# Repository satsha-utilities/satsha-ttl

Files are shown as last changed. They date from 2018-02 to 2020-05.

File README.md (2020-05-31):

<div align="center"><h1 style="font-family: courier;" align="center">satsha-ttl</h1></div>

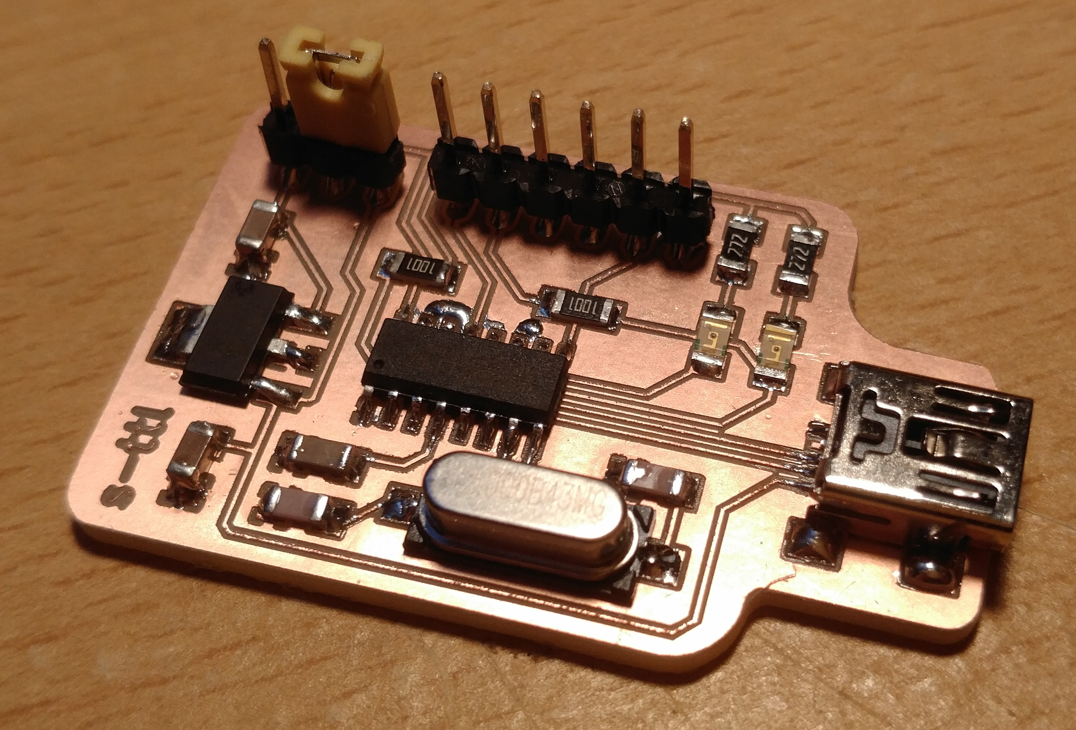
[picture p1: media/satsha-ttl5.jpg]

<div align="center"><i>An open source & fabbable USB to serial converter board.</i></div>

satsha-ttl
--

After some time of buying expensive FDTI cables (about 20$ nowadays) and having the need to use several USB to serial converters for my **[Fab Academy](http://fabacademy.org/)** students, I developed my own fabbable solution. satsha-ttl features a **[CH340G USB to serial chip](https://cdn.sparkfun.com/datasheets/Dev/Arduino/Other/CH340DS1.PDF)** and it is designed to be cheap, reliable and easy to be reproduced. It uses an LDO voltage regulator and a **jumper to switch between 3.3V and 5V**, both for power and logic levels of TX/RX. The design of the satsha-ttl also allows to easily integrate it into existing boards requiring an USB communication without having a dedicated hardware implemented into the microcontroller (eg the 328p).

Here are the **features of the satsha-ttl:**

- **CH340G** USB to serial chip
- selectable voltage of **3.3V and 5V** (both for power and serial)
- **250mA** current on 3.3V
- **USB power** for 5V
- **CTS and DTR** pins
- **mini USB** connector
- **no drivers** needed for latest Windows/MacOS/Linux
- size of **45x28mm**
- cost **1.3€/1.6$** (buying the components from China, **[BOM](https://gitlab.fabcloud.org/satsha/satsha-ttl/raw/master/docs/satsha-ttl-BOM.xlsx)**)

satsha-ttl **PCB**:

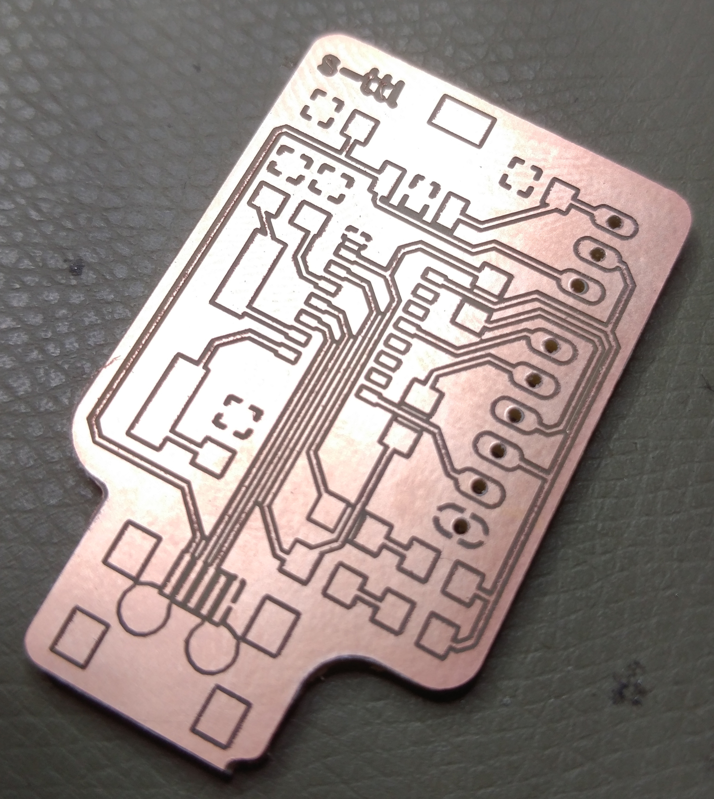
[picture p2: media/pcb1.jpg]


satsha-ttl **schematic**:

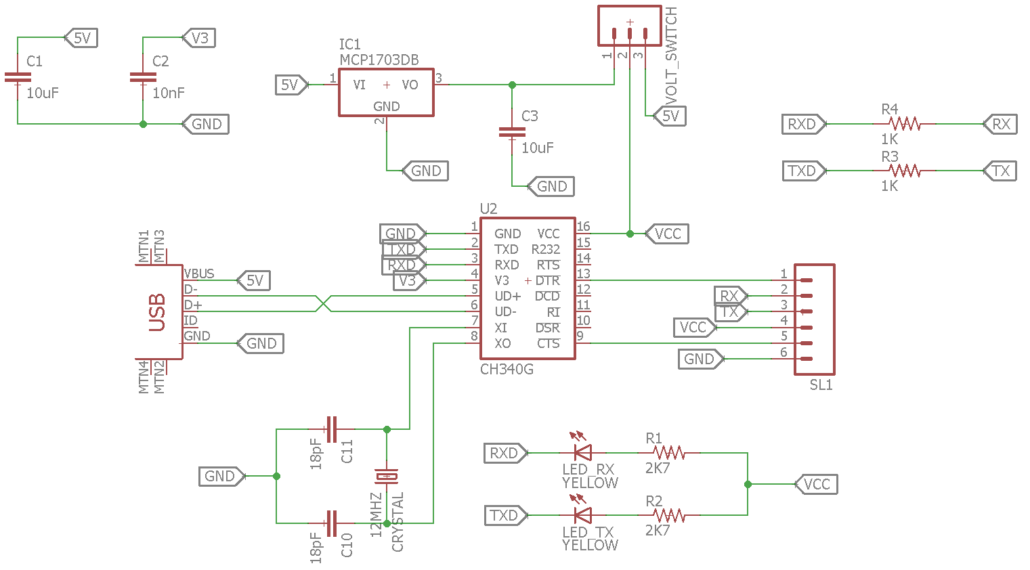
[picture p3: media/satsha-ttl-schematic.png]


satsha-ttl **board**:

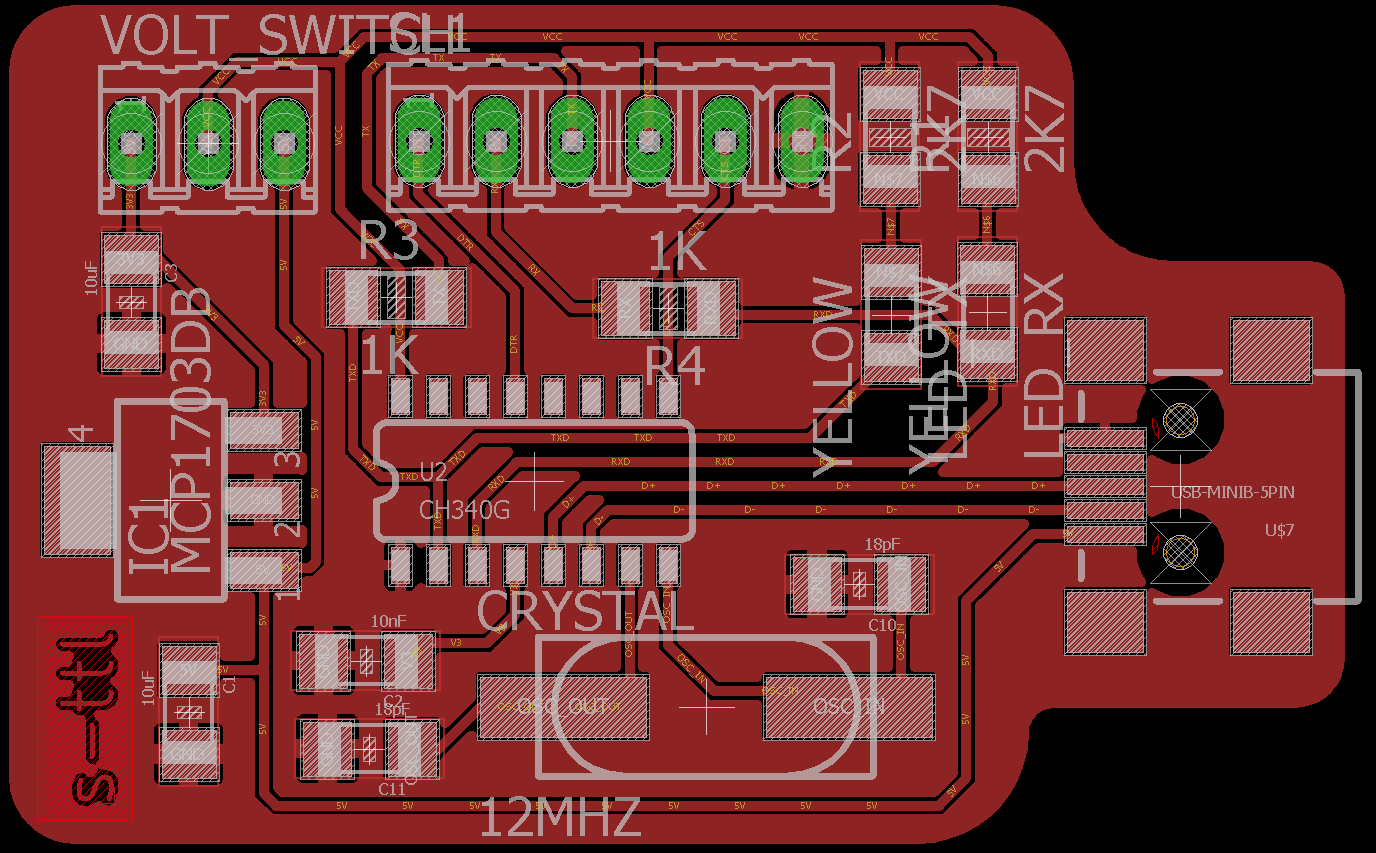
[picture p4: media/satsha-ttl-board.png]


Downloads
--

**downloads (right click download as):**

- **[satsha-ttl schematic](https://github.com/satsha-utilities/satsha-ttl/raw/master/eagle/satsha-ttl/satsha-ttl.sch)**
- **[satsha-ttl board](https://github.com/satsha-utilities/satsha-ttl/raw/master/eagle/satsha-ttl/satsha-ttl.brd)**
- **[satsha-ttl internal traces png 0.1mm](https://github.com/satsha-utilities/satsha-ttl/raw/master/media/internal.png)**
- **[satsha-ttl cutout png 0.1mm](https://github.com/satsha-utilities/satsha-ttl/raw/master/media/cut.png)**
- **[satsha-ttl internal traces png 0.2mm](https://github.com/satsha-utilities/satsha-ttl/raw/master/media/internal_02.png)**
- **[satsha-ttl cutout png 0.2mm](https://github.com/satsha-utilities/satsha-ttl/raw/master/media/cut_02.png)**
- **[satsha-ttl BOM ods](https://github.com/satsha-utilities/satsha-ttl/raw/master/docs/satsha-ttl-BOM.ods)**
- **[satsha-ttl BOM xlsx](https://github.com/satsha-utilities/satsha-ttl/raw/master/docs/satsha-ttl-BOM.xlsx)**

Getting started with satsha-ttl
--
Before connecting satsha-ttl to your computer is really important to **check if the connections are ok**, as it could damage the USB port of our computer if they are wrong. A smoke test can also be done beforehand with an **USB hub or an USB power supply**.  Install the **drivers** for the CH340G if satsha-ttl is not recognized automatically from your OS. In case you are using Windows 8 or older, or older versions of MacOS/Linux download and install the **[drivers from here](https://sparks.gogo.co.nz/ch340.html)**. 

 Find below the **satsha-ttl pinout**:

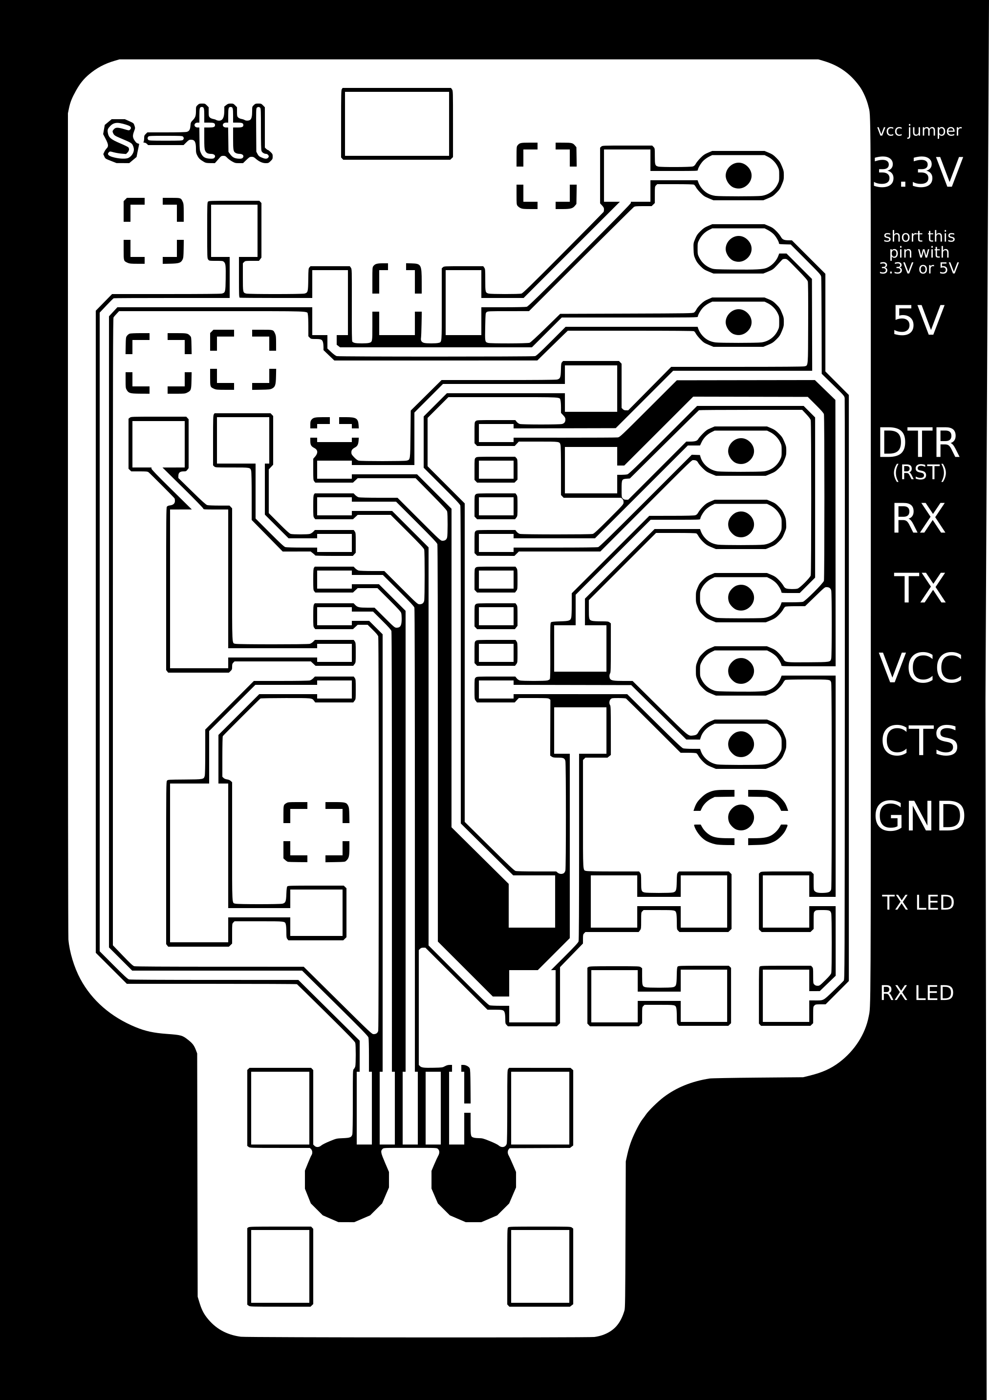
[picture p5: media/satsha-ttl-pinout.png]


satsha-ttl can be used to **supply power** to another microcontroller board, other than connecting the serial. In case of supplying power to another board make sure its voltage and current requirements matches the **selected voltage** on the satsha-ttl jumper and the **maximum current** the satsha-ttl/USB port can output. It is possible to use the satsha-ttl as a **programmer for AVR** microcontrollers with installed the Arduino bootloader, in this case the **DTR** is used **software reset** pin.

Here is an example scheme on how to connect **satsha-ttl to program a satshakit:**

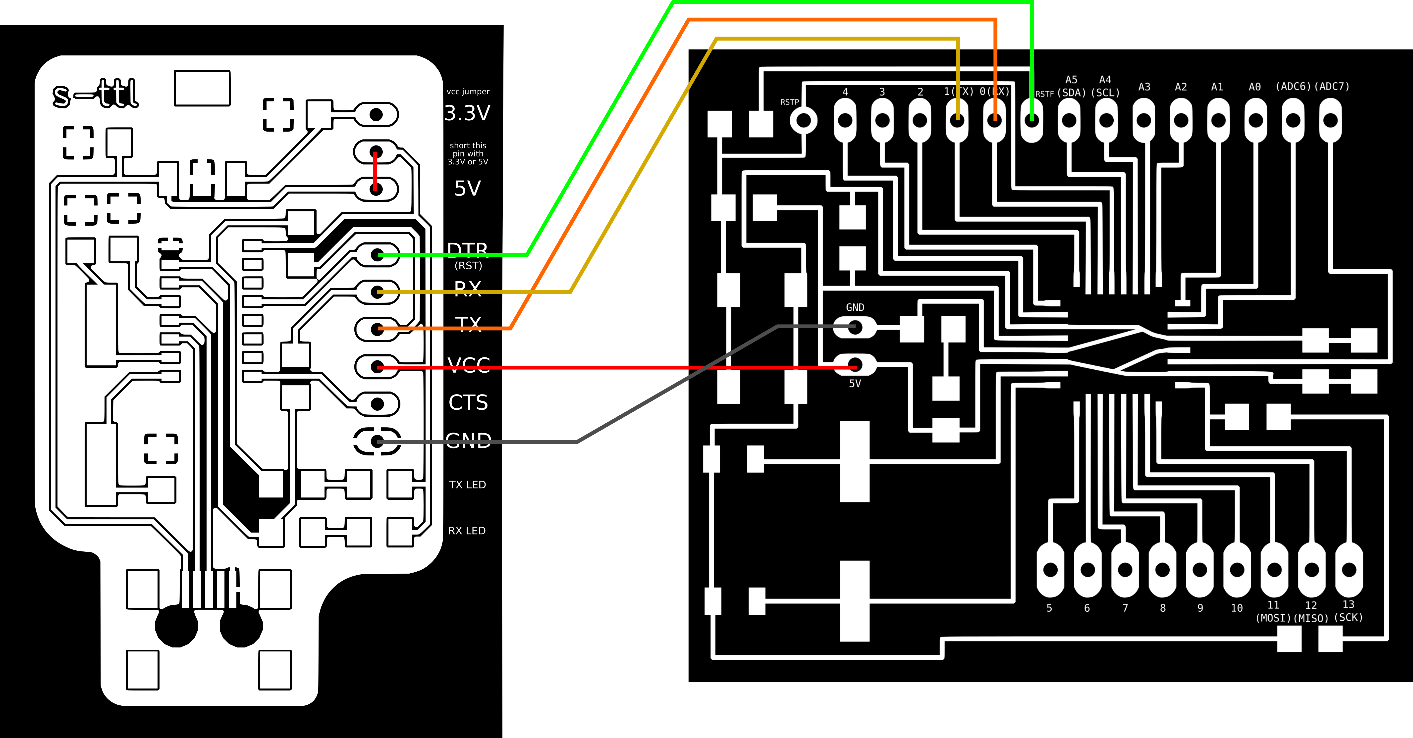
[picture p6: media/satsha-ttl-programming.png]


Media
--

satsha-ttl pictures:

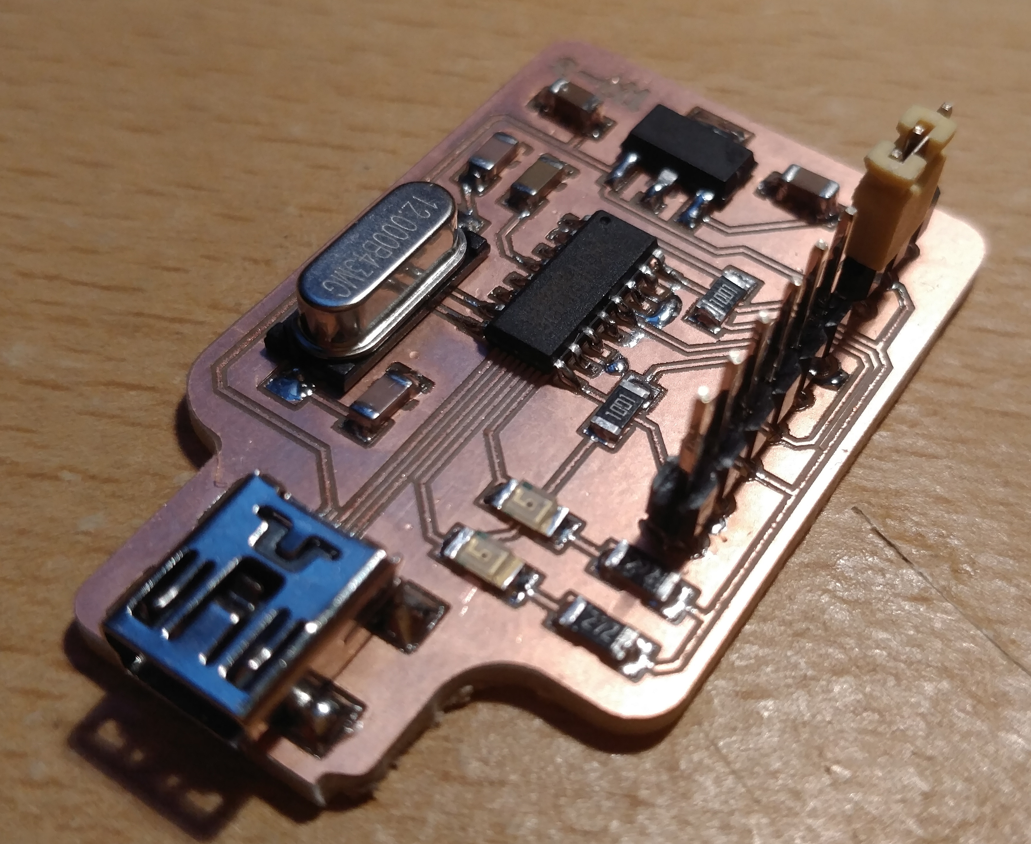
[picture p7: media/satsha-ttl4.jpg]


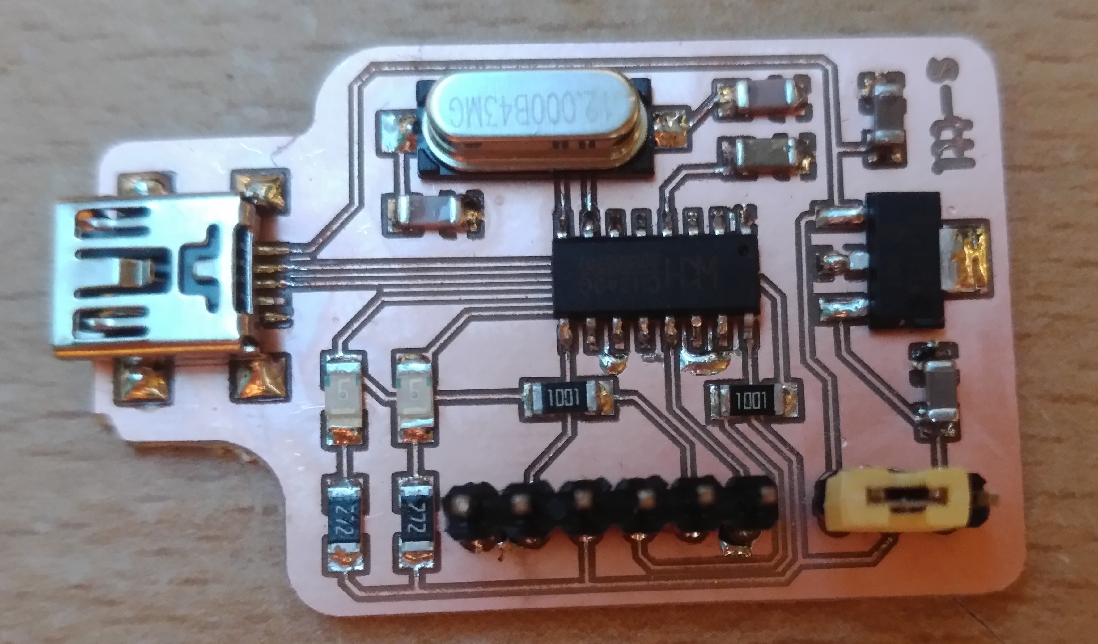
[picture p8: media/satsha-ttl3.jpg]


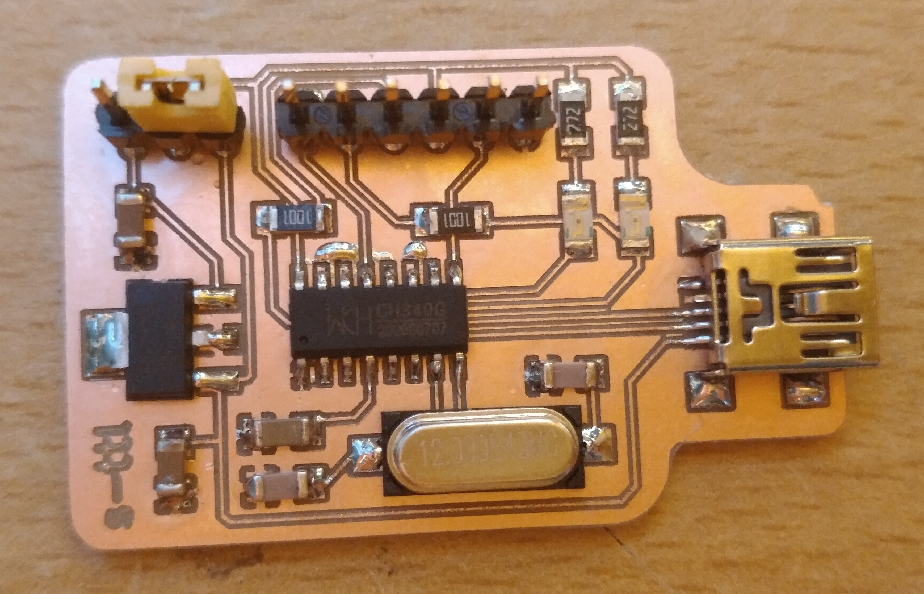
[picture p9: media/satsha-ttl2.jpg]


satsha-ttl connected with a satshakit:

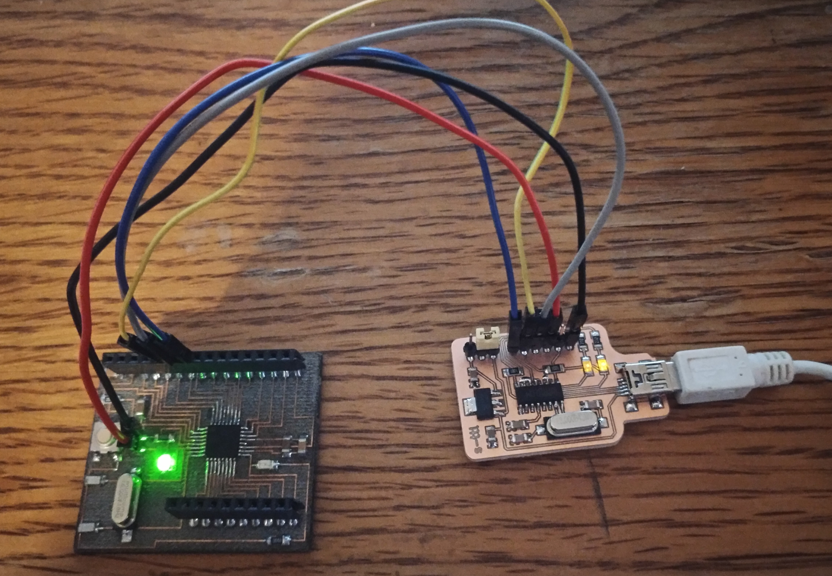
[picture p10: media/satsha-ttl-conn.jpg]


satsha-ttl 1 million lines gcode test:

<a href="http://www.youtube.com/watch?feature=player_embedded&v=dIH6fnEvGS4
" target="_blank"></a>

satsha-ttl 2 uploading to a satshakit using serial 5V:

<a href="http://www.youtube.com/watch?feature=player_embedded&v=kN5nttG7nbE
" target="_blank"></a>

satsha-ttl receiving data from software serial 3.3V:

<a href="http://www.youtube.com/watch?feature=player_embedded&v=gNB7xQKvWcM
" target="_blank"></a>

satsha-ttl streaming gcode to grbl satshakit @250000 bauds 5V:

<a href="http://www.youtube.com/watch?feature=player_embedded&v=7HWK96QzLX8
" target="_blank"></a>

Author
--

- Daniele Ingrassia

Contact
--
- **ingrassiada@gmail.com**
- **[linkedin](http://it.linkedin.com/in/danieleingrassia)**

Thanks
--
[Fablab Kamp-Lintfort](http://fablab.hochschule-rhein-waal.de/index.php/de/)<br />
Hochschule Rhein-Waal<br />
Friedrich-Heinrich-Allee 25, 47475 Kamp-Lintfort, Germany<br />
fablab@hochschule-rhein-waal.de

License
--
This work is licensed under the terms of the open source license: Creative Commons Attribution-ShareAlike 4.0 International ([CC BY-SA 4.0](https://creativecommons.org/licenses/by-sa/4.0/)).

Disclaimer  
--

<div class="align-justify">
This hardware/software is provided "as is", and you use the hardware/software at your own risk. Under no circumstances shall any author be liable for direct, indirect, special, incidental, or consequential damages resulting from the use, misuse, or inability to use this hardware/software, even if the authors have been advised of the possibility of such damages.</div>

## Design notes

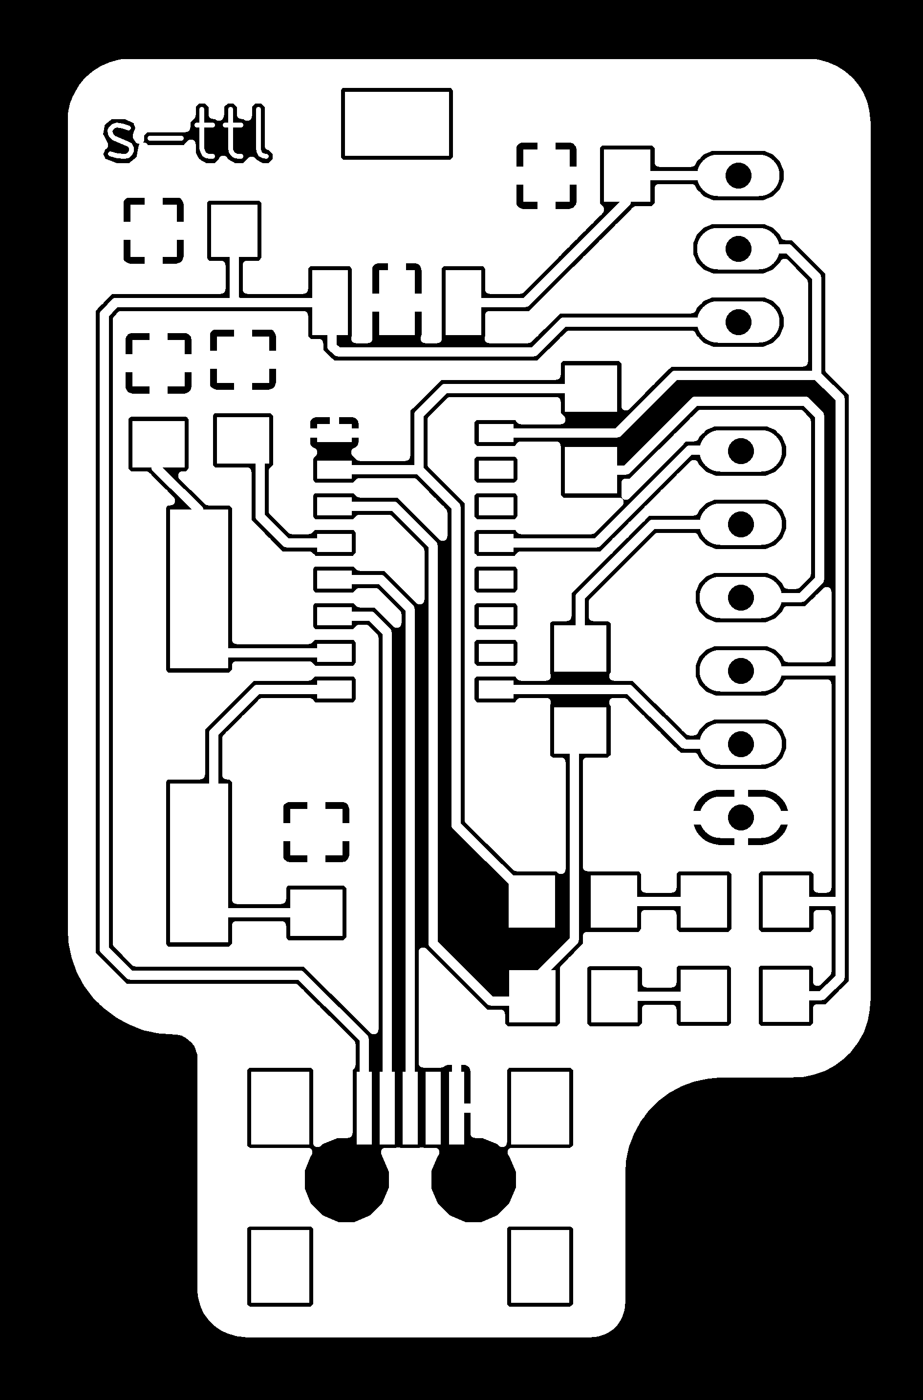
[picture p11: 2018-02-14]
media/internal.png

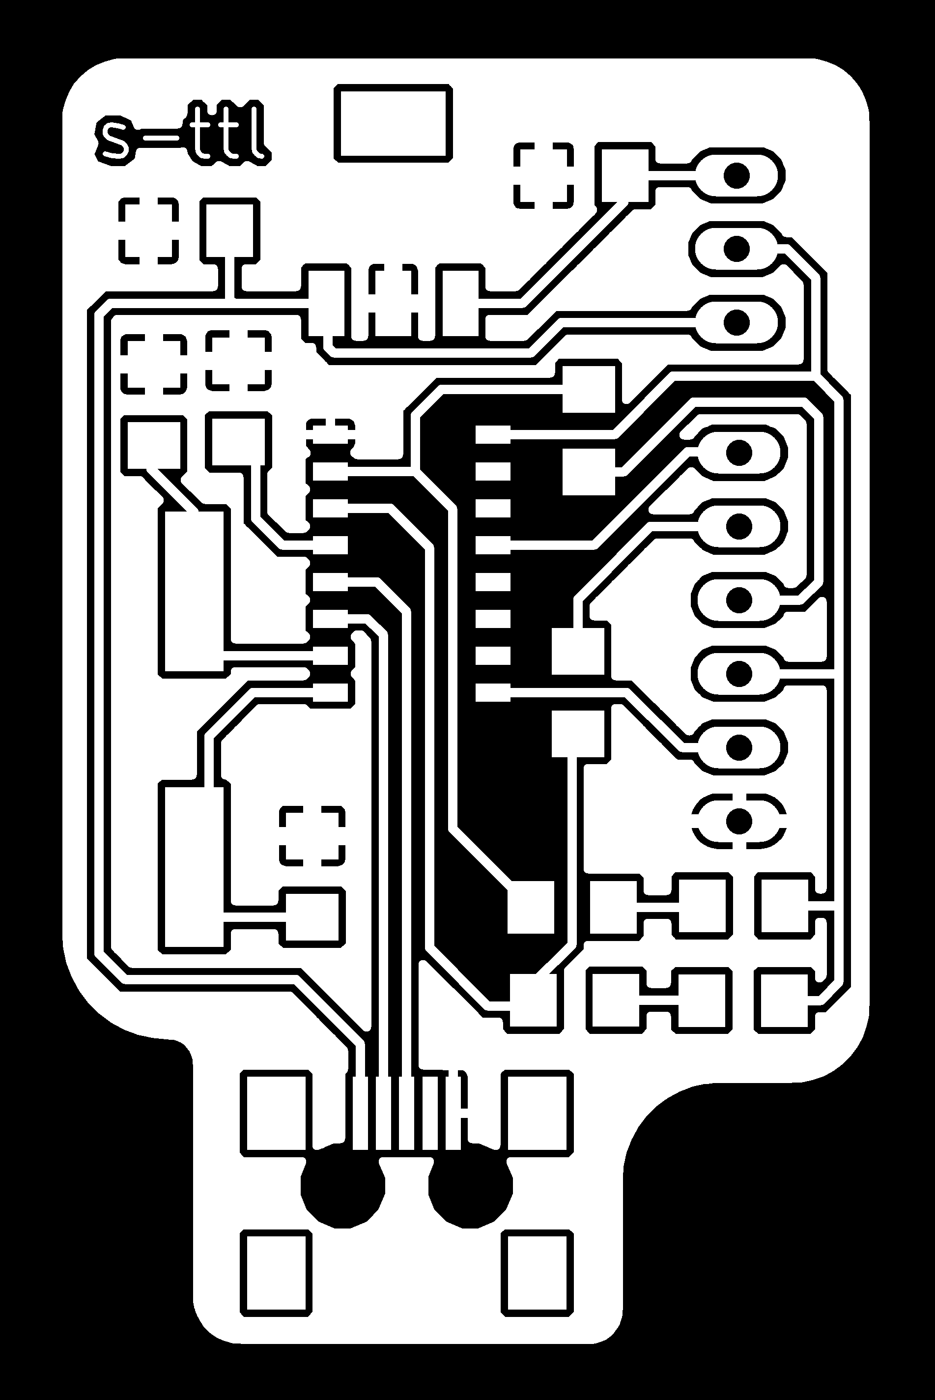
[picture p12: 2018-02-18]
media/internal_02.png

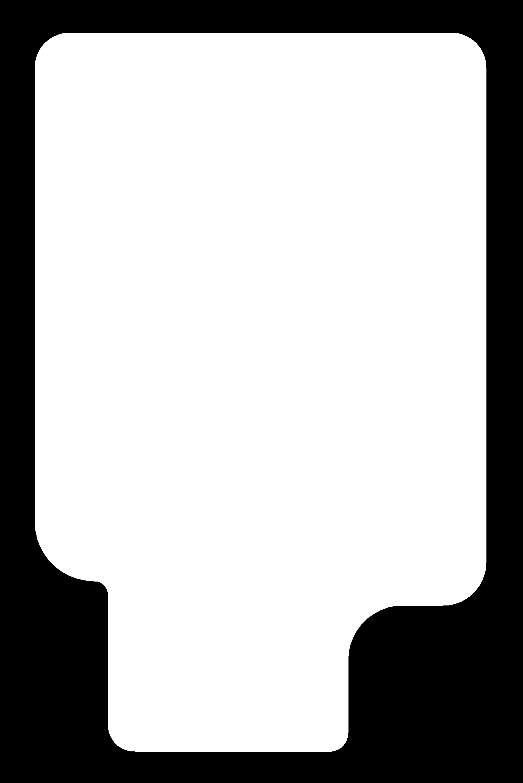
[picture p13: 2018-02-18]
media/cut_02.png

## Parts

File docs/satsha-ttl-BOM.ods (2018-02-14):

Quantity | Description | Unit Price | Extended Price
1 | Mini USB connector (https://www.aliexpress.com/item/ZLinKJ-Wholesale-10pcs-lot-Mini-Usb-Connector-Micro-USB-Connector-5pin-Seat-Jack-Micro-Usb-Four/32840263513.html) | 0.043 | 0.04€
2 | Yellow LED 1206 (https://www.aliexpress.com/item/50PCS-Free-Shipping-SMD-1206-LED-YELLOW-Ultra-Bright-SMD-LEDs-1206-yellow-1206-Diodes-light/1000004897034.html) | 0.0092 | 0.02€
2 | Capacitor 18pF 1206 (https://www.aliexpress.com/item/1206-18PF-50V-180J-5-100pcs-lot-Free-shipping-SMD-ceramic-capacitors/32826160763.html) | 0.018 | 0.04€
1 | Capacitor 10nF 1206 (https://www.aliexpress.com/item/500PCS-1206-103-10NF-0-01UF-X7R-10-smd-chip-capacitor/1478495946.html) | 0.0096 | 0.01€
2 | Resistor 1K 1206 (https://www.aliexpress.com/item/Free-Shipping-100PCS-1206-1K-1K-OHM-1-smd-resistor/1090880725.html) | 0.0074 | 0.01€
1 | Pin Header 0.1" 40pos (https://www.aliexpress.com/item/10pcs-40-Pin-1x40-Single-Row-Male-2-54-Breakable-Pin-Header-Connector-Strip-for-Arduino/32555149083.html) | 0.045 | 0.05€
2 | Resistor 2K71206 (https://www.aliexpress.com/item/200pcs-lot-SMD-Chip-Resistor-1206-2K-2-2K-2-4K-2-7K-3K-Ohm-5/32832679594.html) | 0.0041 | 0.01€
1 | Crystal 12Mhz (https://www.aliexpress.com/item/1LOT-10PCS-Crystal-12MHZ-20PF-20PPM-2P-49SMD-SeriesHC-49SMD/32536483181.html) | 0.195 | 0.20€
2 | Capacitor 10uF 1206 (https://www.aliexpress.com/item/Free-shipping-100pcs-1206-10uF-16V-20-Y5V-Ceramic-SMD-Capacitor/1225771436.html) | 0.0102 | 0.02€
1 | 0.1" Jumper (https://www.aliexpress.com/item/OOTDTY-100-Pcs-2-54mm-Standard-Jumper-Blocks-Caps-For-Hard-Drive-CD-DVD-Motherboards-High/32845598684.html) | 0.0066 | 0.01€
1 | MCP1703DB 3.3V 250mA Regulator (https://www.aliexpress.com/item/MCP1703T-3302E-DB-MCP1703T-3302E-D-MCP1703T-3302E-MCP1703T-3302-3302-10pcs-lot/32762444428.html) | 0.261 | 0.26€
1 | CH340G Usb to Serial converter (https://www.aliexpress.com/item/Free-shipping-1pcs-CH340G-CH340-SOP-16-The-new-quality-is-very-good-work-100-of/32838726117.html) | 0.62 | 0.62€
 |  | Total: | 1.28€

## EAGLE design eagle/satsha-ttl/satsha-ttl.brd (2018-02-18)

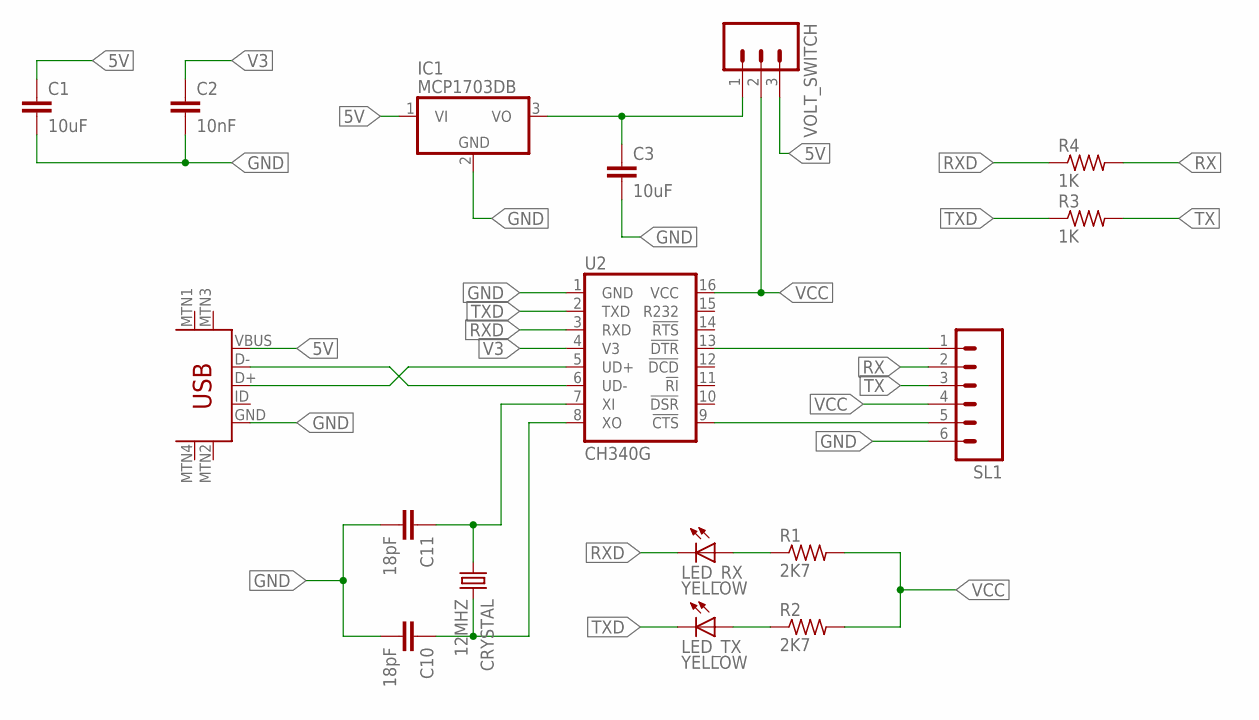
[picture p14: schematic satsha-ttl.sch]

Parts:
C1, C3: 10uF; 1206
C2: 10nF; 1206
C10, C11: 18pF; 1206
CRYSTAL: 12MHZ; CSM-7X-DU
IC1: MCP1703DB; SOT223
LED_RX: YELLOW; LED1206
LED_TX: YELLOW; LED1206
R1, R2: 2K7; R1206
R3, R4: 1K; R1206
SL1: M06; 06P
U2: CH340G; SO016
U$7: USB-MINIB-5PIN; USB-MINIB
VOLT_SWITCH: M03; 03P

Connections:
3V3: C3.1, IC1.3 (VO), VOLT_SWITCH.1
5V: C1.1, IC1.1 (VI), U$7.VBUS, VOLT_SWITCH.3
CTS: SL1.5, U2.9 (!CTS)
D+: U2.5 (UD+), U$7.D+
D-: U2.6 (UD-), U$7.D-
DTR: SL1.1, U2.13 (!DTR)
GND: C1.2, C2.2, C3.2, C10.2, C11.2, IC1.2 (GND), SL1.6, U2.1 (GND), U$7.GND
unnamed: LED_RX.1 (A), R1.1
unnamed: LED_TX.1 (A), R2.1
OSC_IN: C10.1, CRYSTAL.2, U2.8 (XO)
OSC_OUT: C11.1, CRYSTAL.1, U2.7 (XI)
RX: R4.2, SL1.2
RXD: LED_RX.2 (C), R4.1, U2.3 (RXD)
TX: R3.2, SL1.3
TXD: LED_TX.2 (C), R3.1, U2.2 (TXD)
V3: C2.1, U2.4 (V3)
VCC: R1.2, R2.2, SL1.4, U2.16 (VCC), VOLT_SWITCH.2

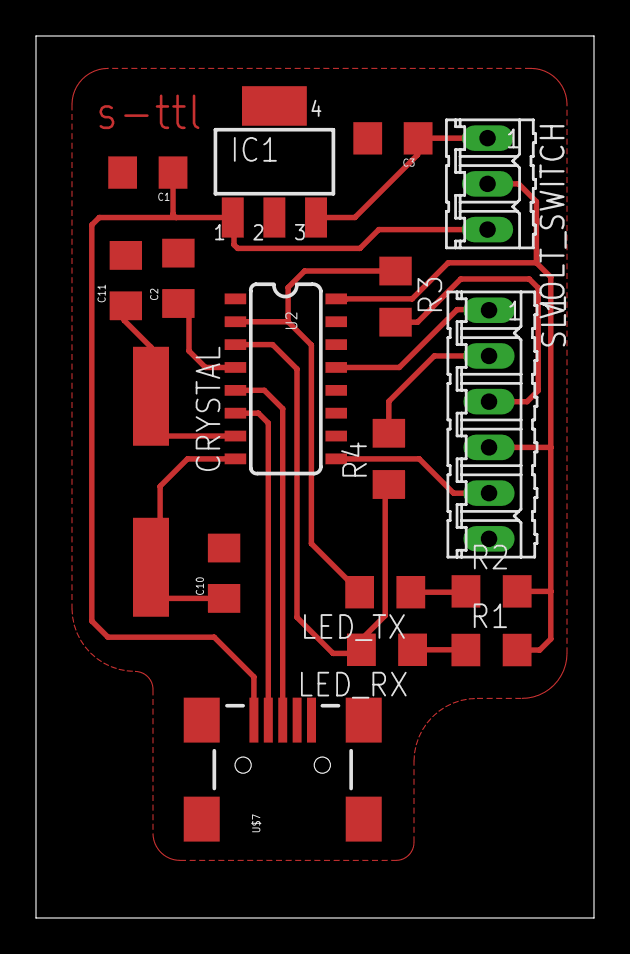
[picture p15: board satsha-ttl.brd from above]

Board: 2 copper layers, 31.0 x 49.0 mm, 17 parts (0 on the bottom side), 17 nets.

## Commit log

2018-02-14 first commit imported from Fab Academy gitlab
    [satsha-ttl-BOM.ods, satsha-ttl-BOM.xlsx, satsha-ttl.brd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]
2018-02-18 added pngs for 0.2mm
    [satsha-ttl.brd]

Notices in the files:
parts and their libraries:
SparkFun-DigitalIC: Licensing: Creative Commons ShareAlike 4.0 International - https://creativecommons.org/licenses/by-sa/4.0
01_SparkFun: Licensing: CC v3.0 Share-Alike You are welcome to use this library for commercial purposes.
